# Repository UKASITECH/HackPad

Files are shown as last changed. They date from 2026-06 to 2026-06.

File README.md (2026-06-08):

# Hackpad

built by Umang Kumar Singh for HackClub 2026

Hackpad is my first crack at a hardware project — a simple macropad with seven keys and a rotary encoder. Seven keys for whatever macros you want (calculator hotkey, anyone?), and the encoder handles volume or media scrubbing.

The body is two 3D-printed shells held together with M3 screws and heat-set inserts, with a translucent acrylic plate sandwiched in between. The plate can be swapped out pretty easily if you ever want to change the look.

Under the hood it runs QMK with two layers — a mix of keys I don't have easy access to on my main keyboard, plus a few keycodes I thought were amusing. The 128x32 OLED scrolls through *very important and relevant* information on loop.

Overall this was a blast. I'd never done PCB design before, and learning KiCad from scratch was surprisingly rewarding. The case was straightforward in CAD, and working around the PCB constraints made for a fun little puzzle. Firmware was the biggest headache, but after digging through QMK and XIAO docs for a while things started clicking. Once the parts arrived, assembly was smooth — I only had to reprint the case once.

9/10. Would build again.

## PCB

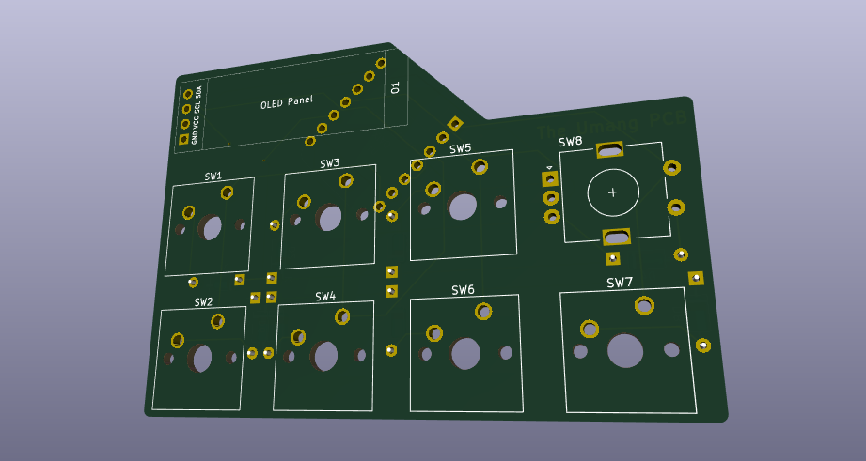
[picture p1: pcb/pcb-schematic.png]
PCB Schematic

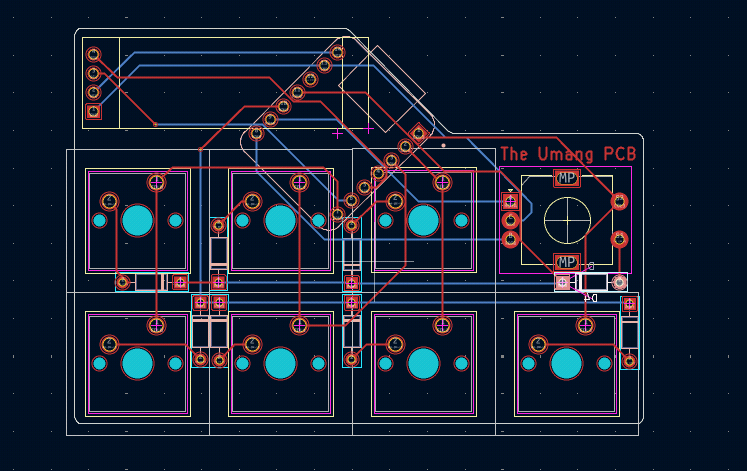
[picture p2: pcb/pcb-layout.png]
PCB Layout


# Bill of materials
- 7x Cherry MX-style keyswitches.
- 4x M3x12mm screws
- 4x M3 X D4.6 X L3.6
- 8x 1N4148 Diodes (through hole)
- 1x EC11 Rotary encoder
- 1x 0.91 inch SSD1306 OLED
- 14x Mill-Max 3305s or 0305s.

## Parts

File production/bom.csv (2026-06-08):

Designator | Footprint | Quantity | Value | LCSC Part #
D1, D2, D3, D4, D5, D6, D7, D8 | D_DO-35_SOD27_P7.62mm_Horizontal | 8 | D
O1 | SSD1306-0.91-OLED-4pin-128x32 | 1 | OLEd
SW1, SW2, SW3, SW4, SW5, SW6, SW7 | SW_Cherry_MX_1.00u_PCB | 7 | SW_Push_45deg
SW8 | RotaryEncoder_Alps_EC11E-Switch_Vertical_H20mm | 1 | RotaryEncoder_Switch
U1 | XIAO-Generic-Thruhole-14P-2.54-21X17.8MM | 1 | Seeed Studio XIAO SAMD21

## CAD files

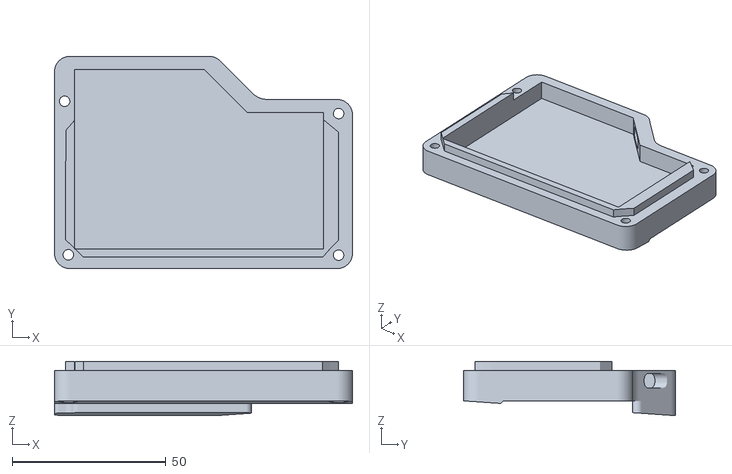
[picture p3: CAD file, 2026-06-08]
cad/case/Jampad-bottom.stl
96.9 x 69.0 x 17.7

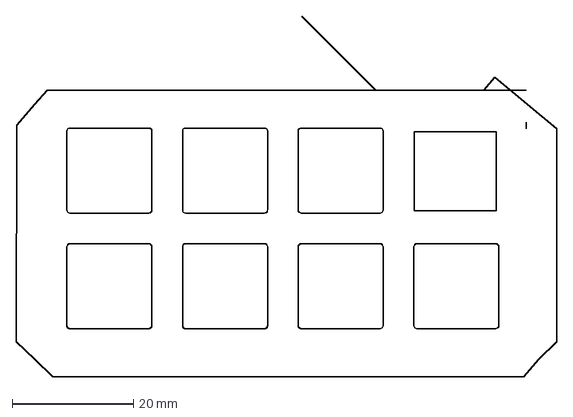
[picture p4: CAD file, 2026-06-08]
cad/Jampad-plate.dxf
89.0 x 59.3 mm

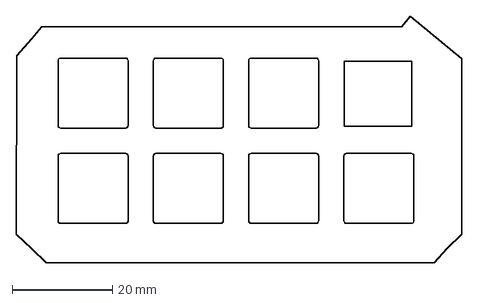
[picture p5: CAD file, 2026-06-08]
cad/case/Jampad-plate.dxf
89.0 x 49.4 mm

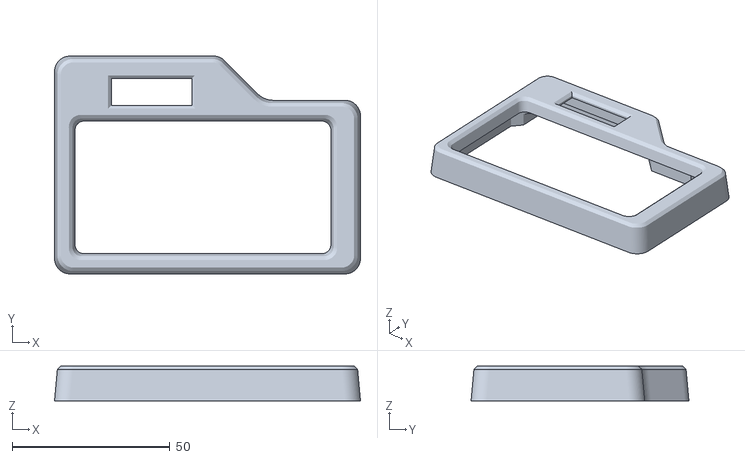
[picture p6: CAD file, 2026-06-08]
cad/case/Jampad-top.stl
96.9 x 69.0 x 11.0

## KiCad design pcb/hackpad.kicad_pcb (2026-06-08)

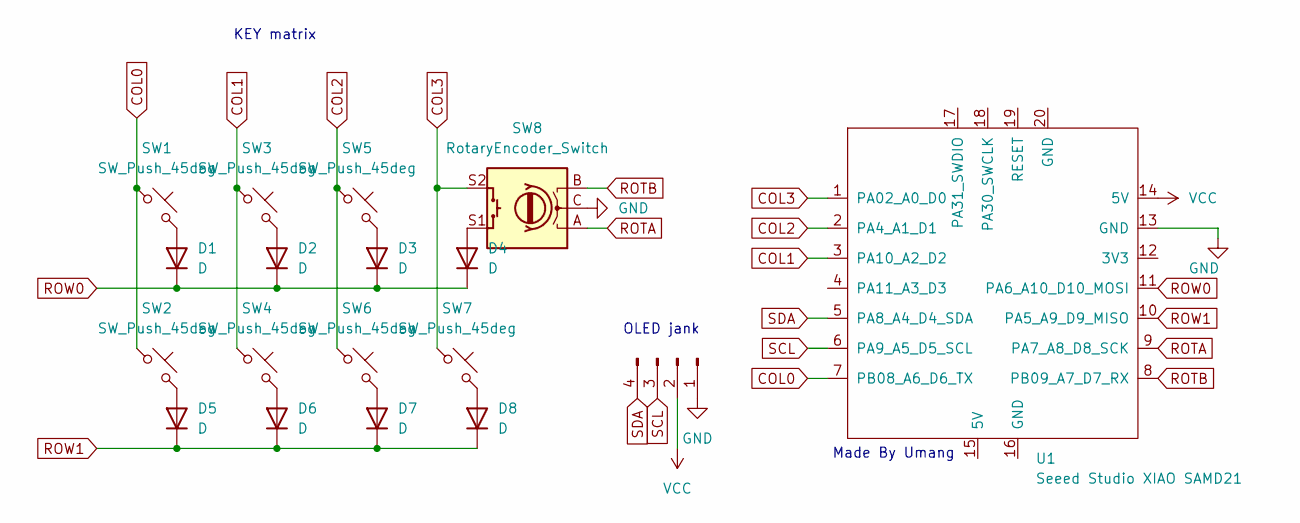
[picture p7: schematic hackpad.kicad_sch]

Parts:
D1, D2, D3, D4, D5, D6, D7, D8: D; D_DO-35_SOD27_P7.62mm_Horizontal
O1: OLEd; SSD1306-0.91-OLED-4pin-128x32
SW1, SW2, SW3, SW4, SW5, SW6, SW7: SW_Push_45deg; SW_Cherry_MX_1.00u_PCB
SW8: RotaryEncoder_Switch; RotaryEncoder_Alps_EC11E-Switch_Vertical_H20mm
U1: Seeed Studio XIAO SAMD21; XIAO-Generic-Thruhole-14P-2.54-21X17.8MM

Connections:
COL0: SW1.1, SW2.1, U1.7 (PB08_A6_D6_TX)
COL1: SW3.1, SW4.1, U1.3 (PA10_A2_D2)
COL2: SW5.1, SW6.1, U1.2 (PA4_A1_D1)
COL3: SW7.1, SW8.S2, U1.1 (PA02_A0_D0)
GND: O1.1, SW8.C, U1.13 (GND)
unnamed: D1.2 (A), SW1.2
unnamed: D2.2 (A), SW3.2
unnamed: D3.2 (A), SW5.2
unnamed: D4.2 (A), SW8.S1
unnamed: D5.2 (A), SW2.2
unnamed: D6.2 (A), SW4.2
unnamed: D7.2 (A), SW6.2
unnamed: D8.2 (A), SW7.2
ROTA: SW8.A, U1.9 (PA7_A8_D8_SCK)
ROTB: SW8.B, U1.8 (PB09_A7_D7_RX)
ROW0: D1.1 (K), D2.1 (K), D3.1 (K), D4.1 (K), U1.11 (PA6_A10_D10_MOSI)
ROW1: D5.1 (K), D6.1 (K), D7.1 (K), D8.1 (K), U1.10 (PA5_A9_D9_MISO)
SCL: O1.3, U1.6 (PA9_A5_D5_SCL)
SDA: O1.4, U1.5 (PA8_A4_D4_SDA)
VCC: O1.2, U1.14 (5V)

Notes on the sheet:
Made By Umang
OLED jank
KEY matrix

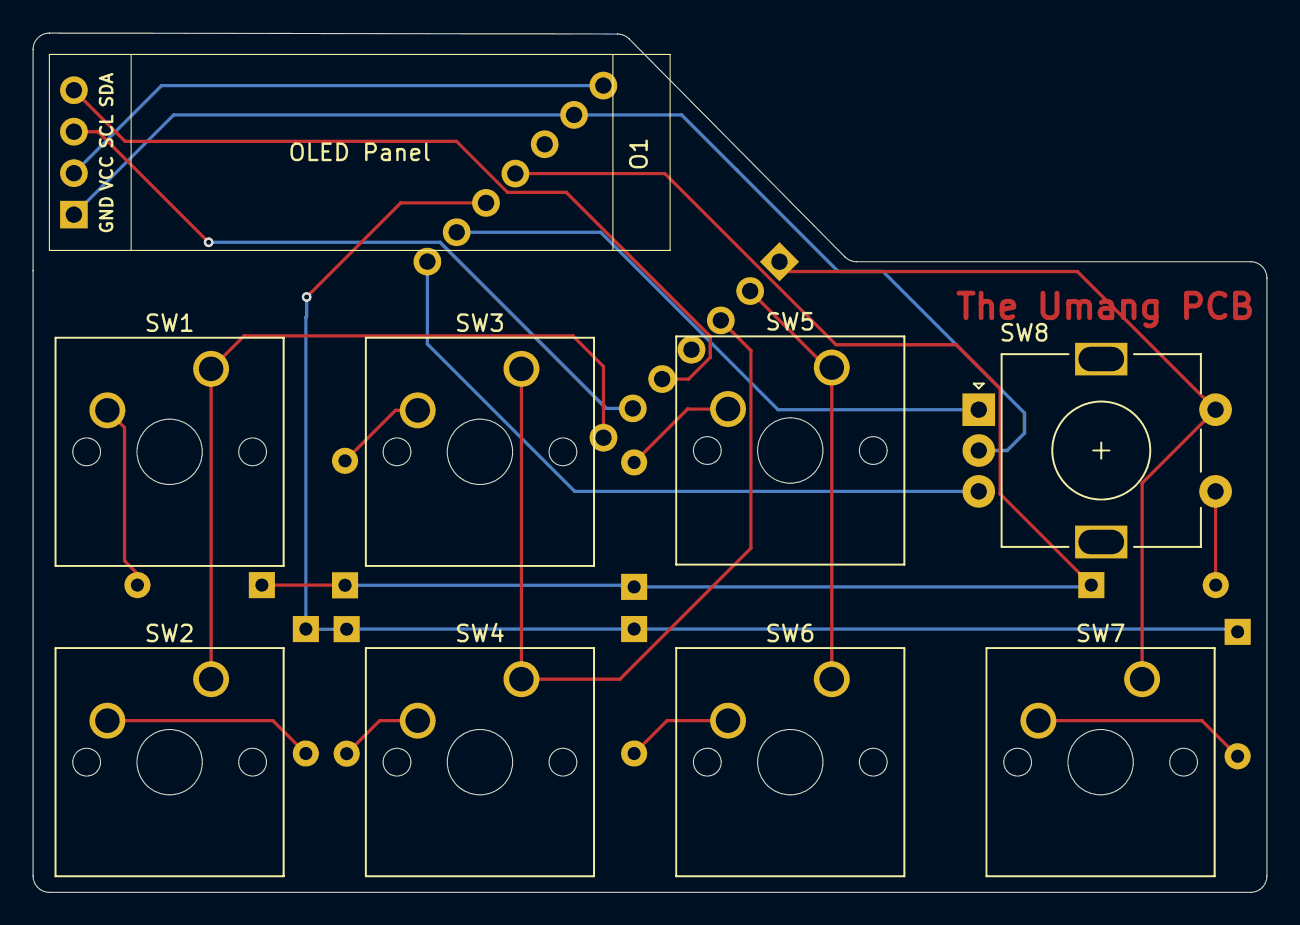
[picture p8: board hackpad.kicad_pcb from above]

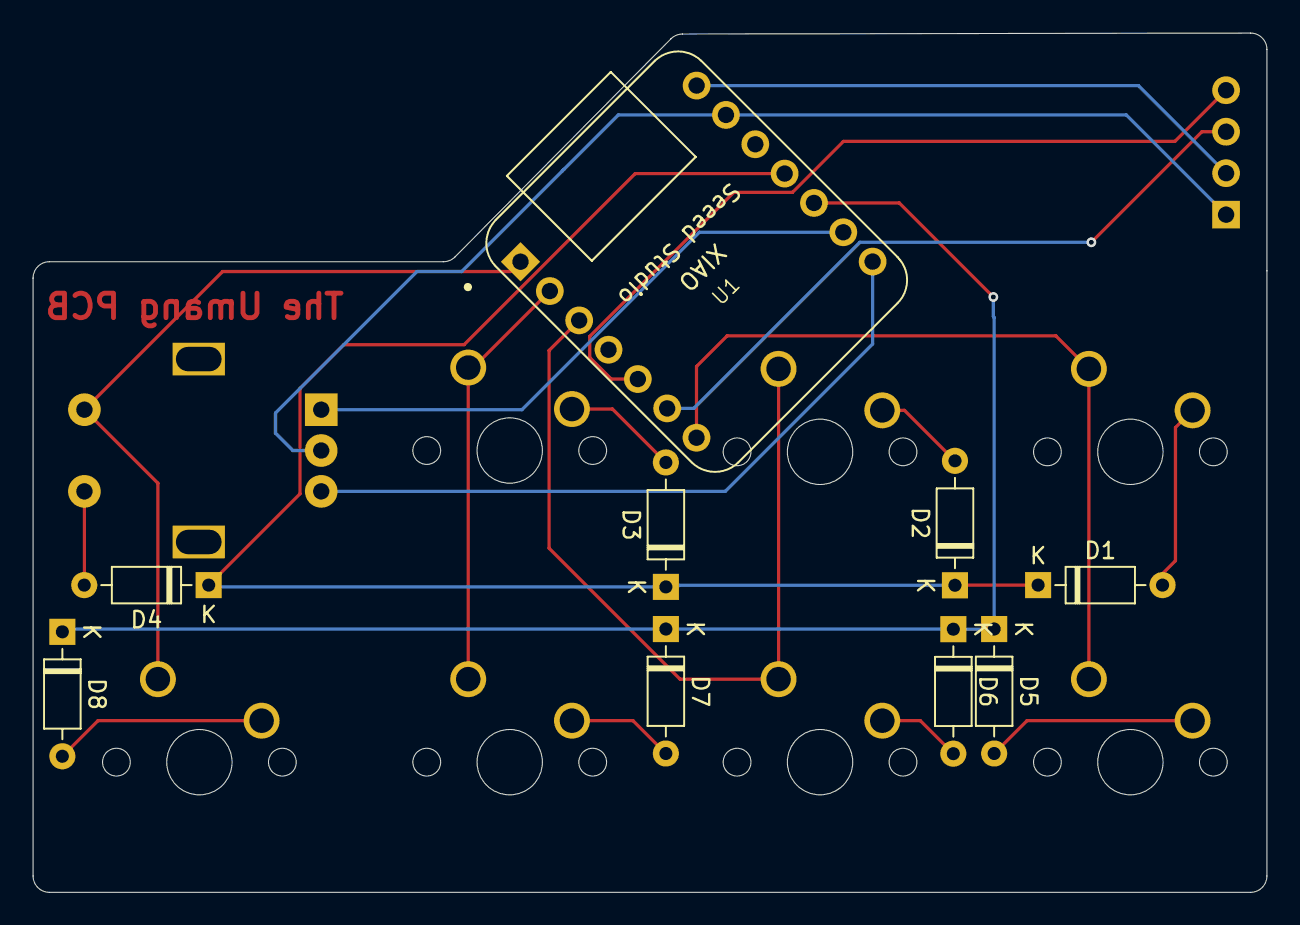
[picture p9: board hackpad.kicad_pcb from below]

Board: 2 copper layers, 75.5 x 52.6 mm, 18 parts (9 on the bottom side), 20 nets.
